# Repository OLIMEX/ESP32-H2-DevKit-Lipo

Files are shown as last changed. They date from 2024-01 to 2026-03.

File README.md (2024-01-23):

# ESP32-H2-DevKit-Lipo
Development board for ESP32-H2 SOC with BLE5 Matter, Thread, Zigbee

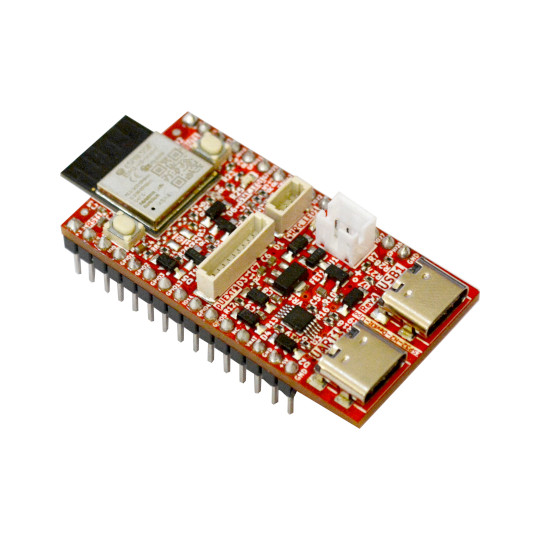
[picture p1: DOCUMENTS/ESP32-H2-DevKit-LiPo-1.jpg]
ESP32-H2-DevKit-LiPo-1


https://www.olimex.com/Products/IoT/ESP32-H2/ESP32-H2-DevKit-LiPo/open-source-hardware

Features:

* ESP32-H1-MINI-1-N4 module
* USB-C with USB to Serial converter for programming / debugging
* USB-C connected directly to ESP32-H2
* LiPo battery charger and connector
* pUEXT connector
* Qwiic/Stemma connector
* Reset button
* User button
* User LED
* all GPIOs available on two headers at 25.4 mm space
* operating temperature -40+85C
* Dimensions: 48 x 25 mm

## Licenses

* Hardware is released under CERN Open Hardware Licence Version 2 - Strongly Reciprocal, all silkscreen credits to Olimex should remain;
* Software is released under GPL3 Licensee
* Documentation is released under CC BY-SA 3.0

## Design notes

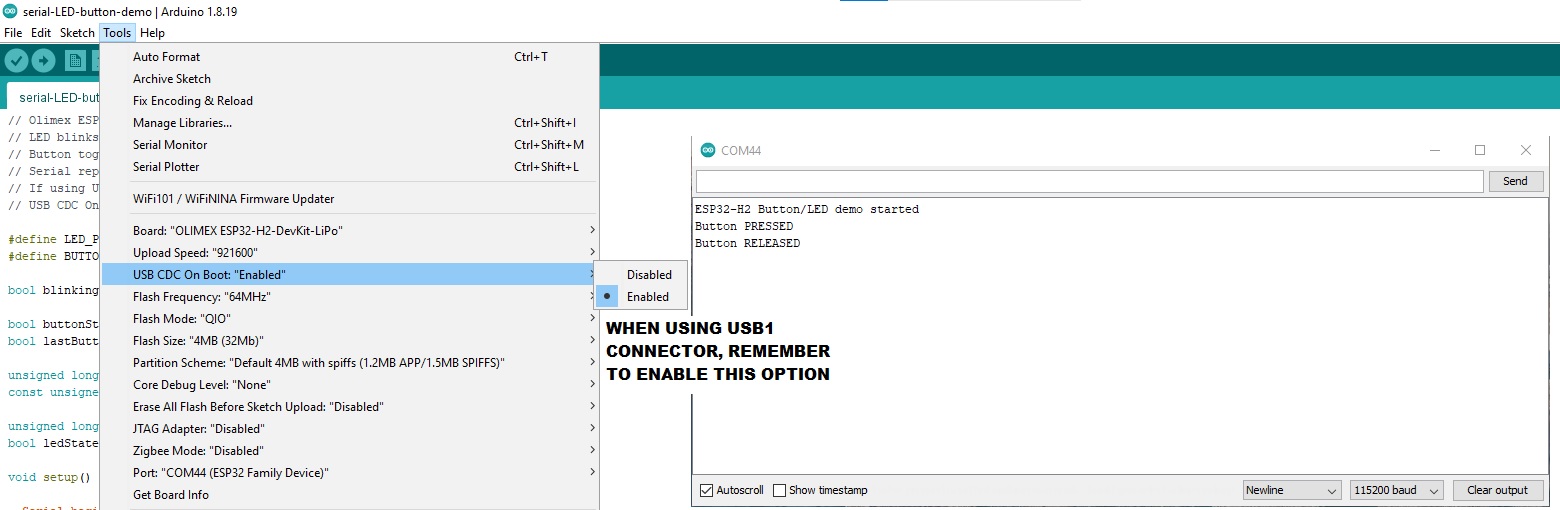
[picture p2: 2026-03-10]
SOFTWARE/ARDUINO/Serial-LED-button-demo/Settings-and-expected-outcome.jpg

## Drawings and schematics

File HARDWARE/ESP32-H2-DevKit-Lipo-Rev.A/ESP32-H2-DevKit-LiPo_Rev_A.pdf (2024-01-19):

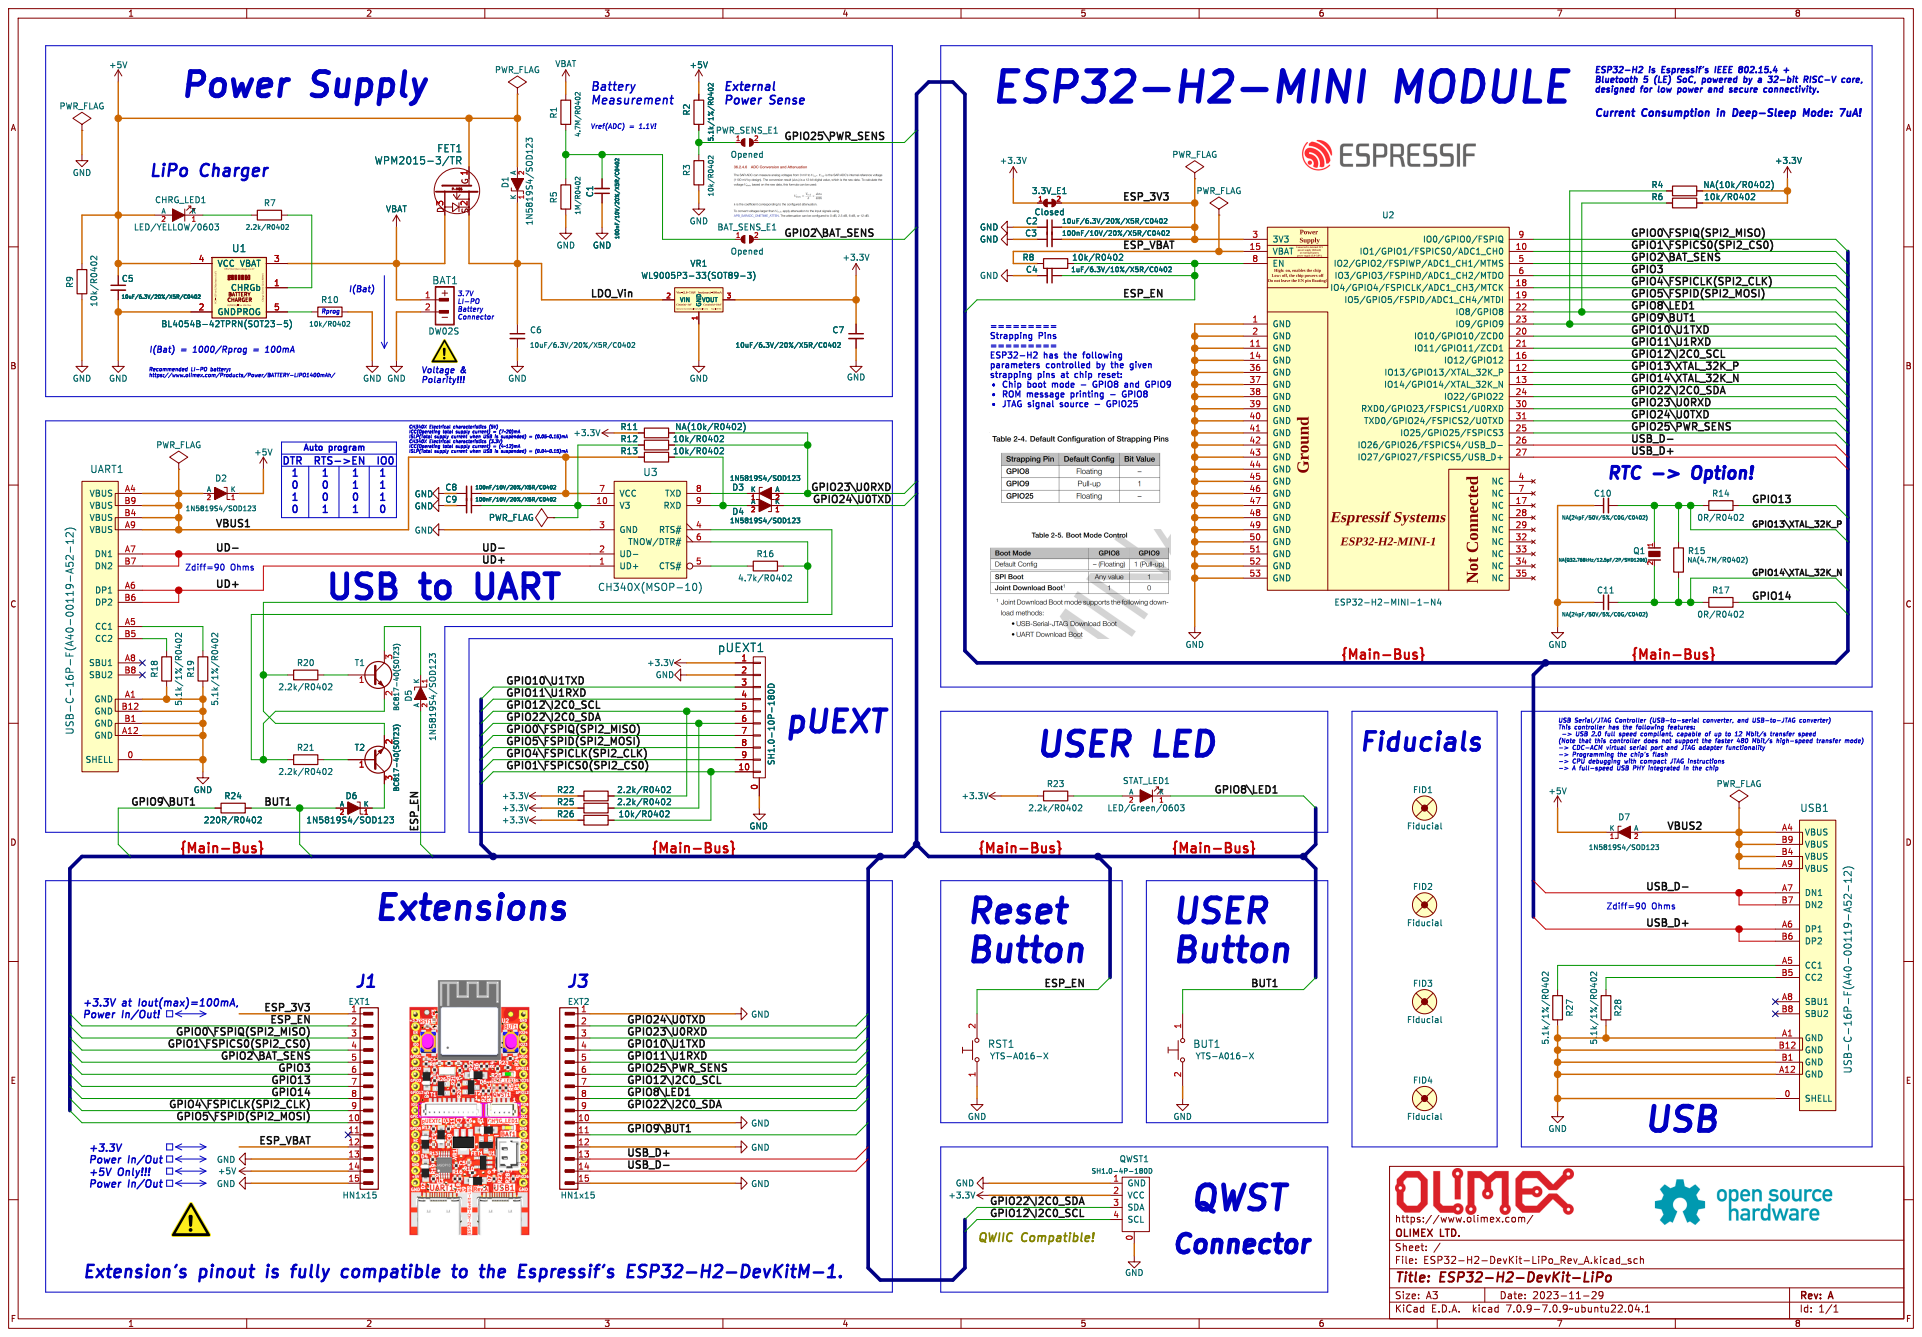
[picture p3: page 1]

Rprog 1. All SMD jumpers closed?

Connectedtointernal3V3 power supply(Default)or externalbatterypower supply(3.0~3.6V). ESP32-H2-MINI-1

QuiescentCurrent(Typ=0.3uA;Max=0.7uA) Topr=-40~85C Vin=(2.0~7.0)V GND

2 D5 1N5819S4/SOD123 C9 100nF/10V/20%/X5R/C0402 UD+ 1 V3 10 UD- 2 GND 3 RTS# 4 CTS# 5 TNOW/DTR# 6 VCC 7 TXD 8 RXD 9 U3 CH340X(MSOP-10) PWR_FLAG

Power In/Out +3.3V at Iout(max)=100mA, Power In/Out!

0 GND 1 VCC 2 SDA 3 SCL 4 QWST1

+5V Only!!! Power In/Out

Id: 1/1 Title: ESP32-H2-DevKit-LiPo

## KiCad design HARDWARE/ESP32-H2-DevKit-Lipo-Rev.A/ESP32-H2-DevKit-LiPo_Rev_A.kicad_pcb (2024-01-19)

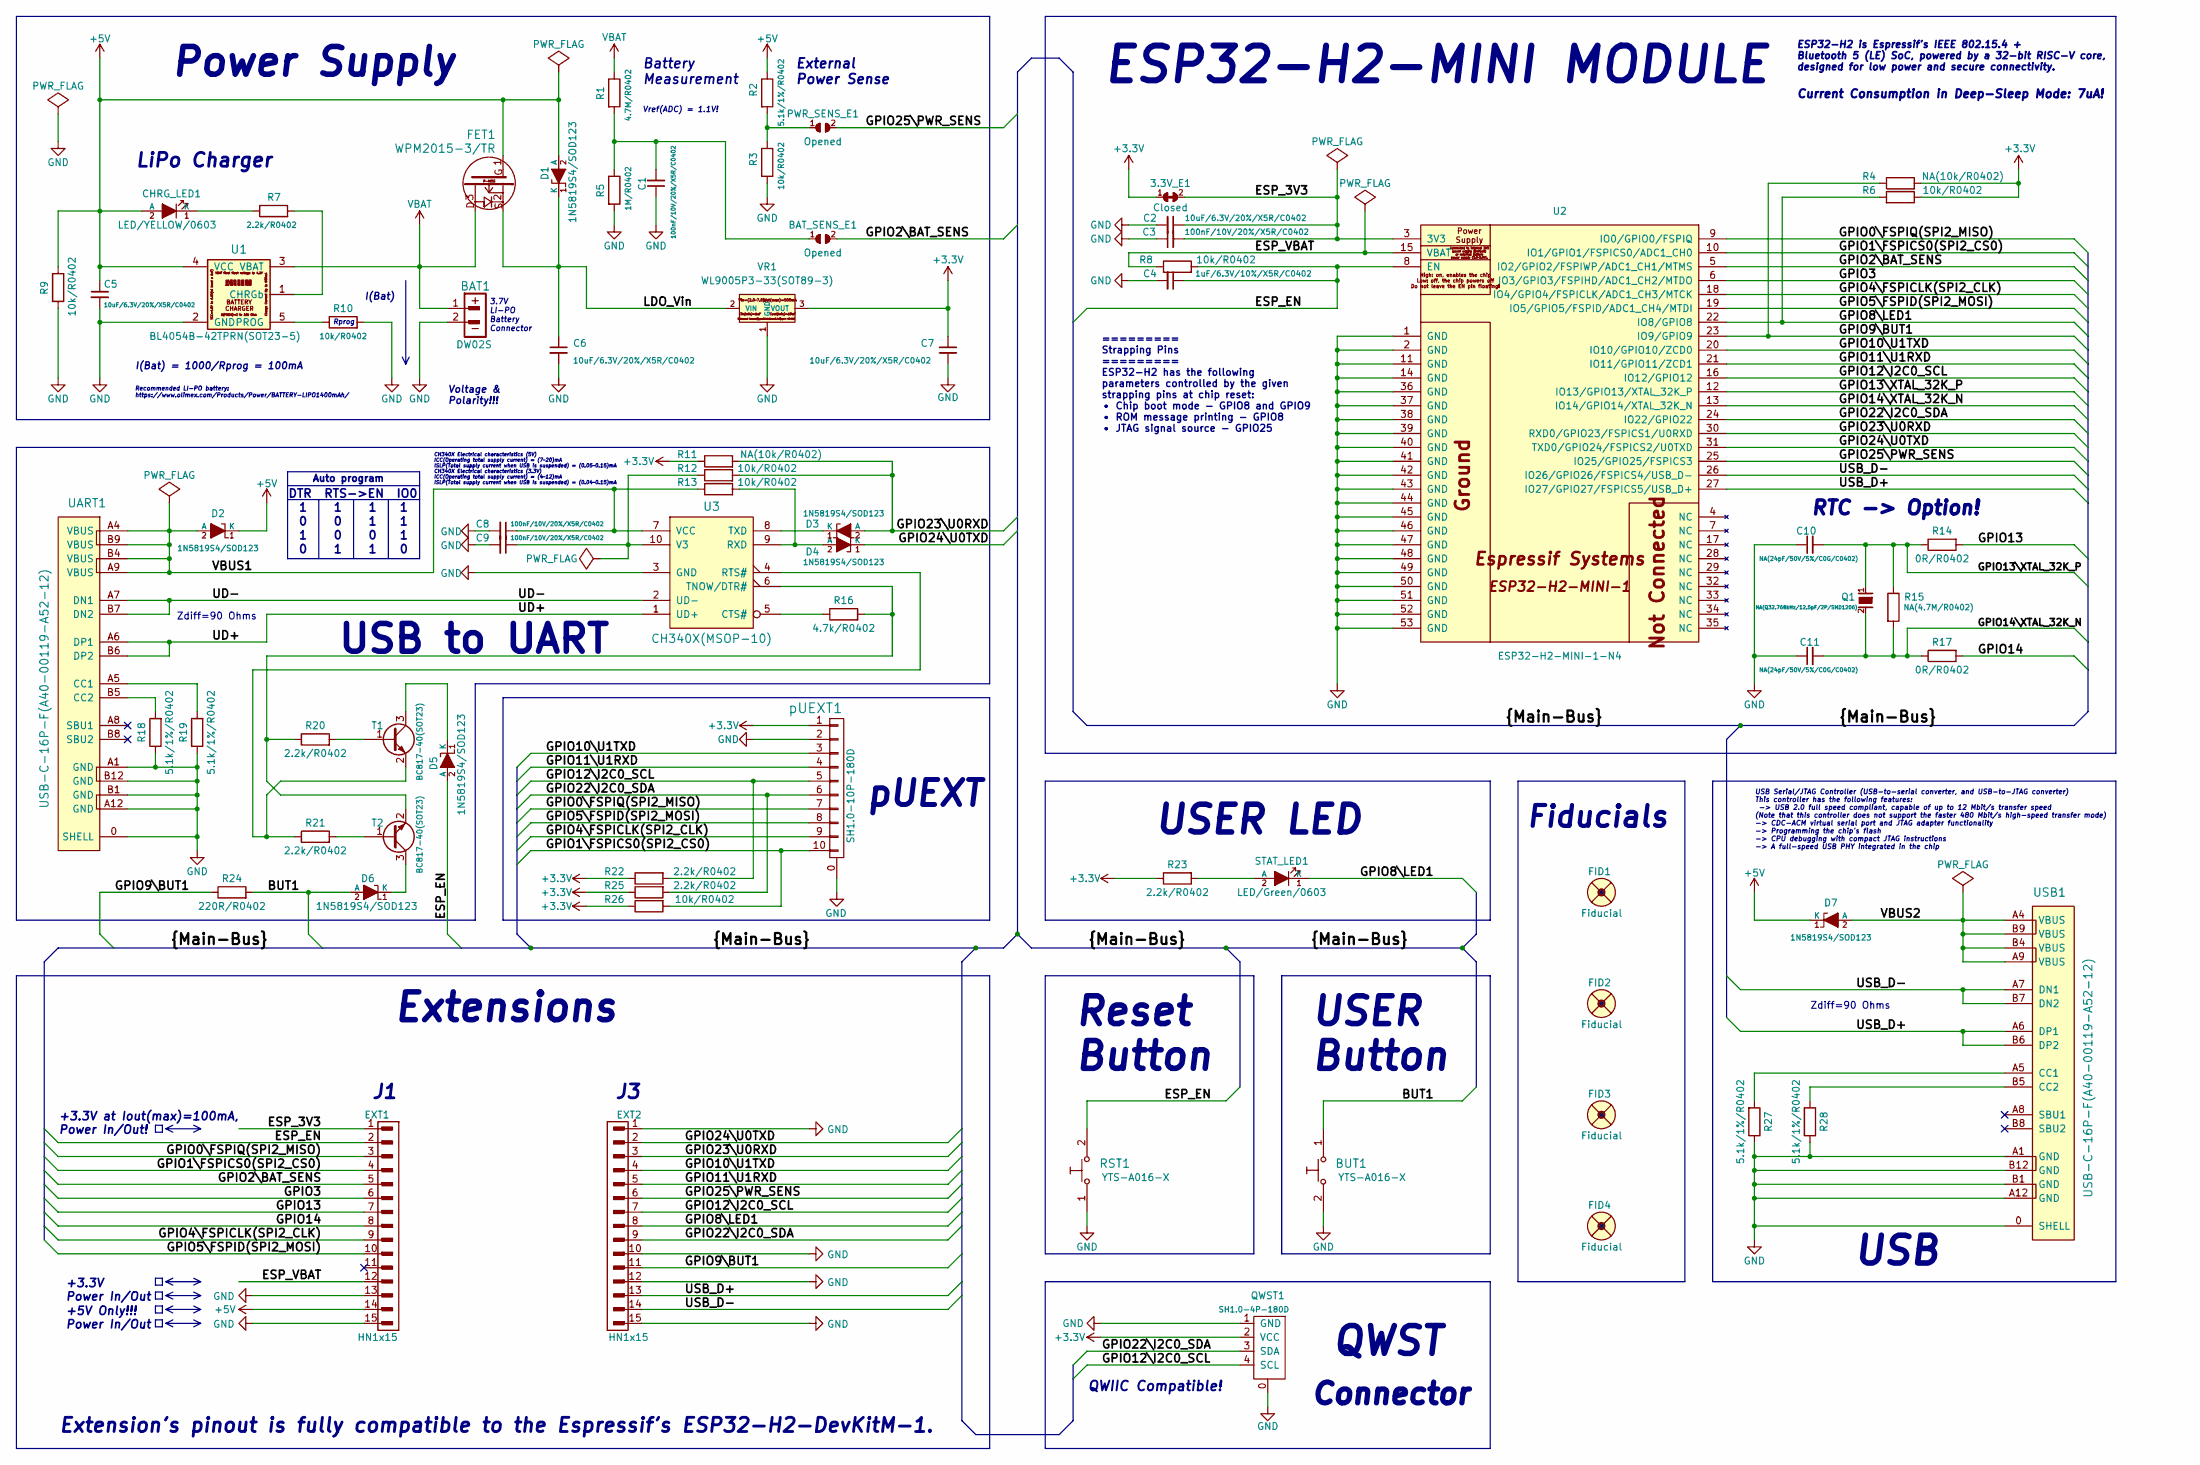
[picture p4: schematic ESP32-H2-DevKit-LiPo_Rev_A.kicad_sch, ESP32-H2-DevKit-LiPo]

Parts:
3.3V_E1: Closed; SJ_Closed
BAT1: DW02S; LIPO_BAT_VERTICAL_DW02S
BAT_SENS_E1: Opened; SJ
BUT1: YTS-A016-X
C1, C3, C8, C9: 100nF/10V/20%/X5R/C0402; C_0402_5MIL_DWS
C2, C5, C6, C7: 10uF/6.3V/20%/X5R/C0402; C_0402_5MIL_DWS
C4: 1uF/6.3V/10%/X5R/C0402; C_0402_5MIL_DWS
C10, C11: NA(24pF/50V/5%/C0G/C0402); C_0402_5MIL_DWS
CHRG_LED1: LED/YELLOW/0603; LED_0603_KA
D1, D2, D3, D4, D5, D6, D7: 1N5819S4/SOD123; SOD-123_1C-2A_KA
EXT1, EXT2: HN1x15
FET1: WPM2015-3/TR; SOT23
FID1, FID2, FID3: Fiducial; Fiducial1x3
FID4: Fiducial; Fiducial1x3_Paste
PWR_SENS_E1: Opened; SJ
Q1: NA(Q32.768kHz/12.5pF/2P/SMD1206); CM7V-T1A(Crystal_Package-1206_3.20x1.50x0.65mm)
QWST1: SH1.0-4P-180D; BM04B-SRSS-TB
R1: 4.7M/R0402; R_0402_5MIL_DWS
R2, R18, R19, R27, R28: 5.1k/1%/R0402; R_0402_5MIL_DWS
R3, R6, R8, R9, R10, R12, R13, R26: 10k/R0402; R_0402_5MIL_DWS
R4, R11: NA(10k/R0402); R_0402_5MIL_DWS
R5: 1M/R0402; R_0402_5MIL_DWS
R7, R20, R21, R22, R23, R25: 2.2k/R0402; R_0402_5MIL_DWS
R14, R17: 0R/R0402; R_0402_5MIL_DWS
R15: NA(4.7M/R0402); R_0402_5MIL_DWS
R16: 4.7k/R0402; R_0402_5MIL_DWS
R24: 220R/R0402; R_0402_5MIL_DWS
RST1: YTS-A016-X
STAT_LED1: LED/Green/0603; LED_0603_KA
T1, T2: BC817-40(SOT23); SOT23
U1: BL4054B-42TPRN(SOT23-5); SOT-23-5
U2: ESP32-H2-MINI-1-N4; ESP32-­C3-­MINI­-1
U3: CH340X(MSOP-10); MSOP-10_Pitch-0.5mm_3.00x3.00x1.00mm
UART1: USB-C-16P-F(A40-00119-A52-12); USB2.0_TYPE-C(A40-00119-A52-12)_Paste
USB1: USB-C-16P-F(A40-00119-A52-12); USB2.0_TYPE-C(A40-00119-A52-12)_Paste
VR1: WL9005P3-33(SOT89-3); SOT89-3
pUEXT1: SH1.0-10P-180D; BM10B-SRSS-TB

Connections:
+3.3V: 3.3V_E1.1, C7.1, QWST1.2 (VCC), R4.2, R6.1, R11.1, R22.1, R23.1, R25.1, R26.1, VR1.3 (VOUT), pUEXT1.1
+5V: C5.1, CHRG_LED1.2 (A), D1.2 (A), D2.1 (K), D7.1 (K), EXT1.14, FET1.1, R2.1, R9.1, U1.4 (VCC)
/BUT1: BUT1.1, D6.2 (A), R24.2
/ESP_3V3: 3.3V_E1.2, C2.1, C3.2, EXT1.1, U2.3 (3V3)
/ESP_EN: C4.1, D5.2 (A), EXT1.2, R8.2, RST1.2, U2.8 (EN)
/ESP_VBAT: EXT1.12, R8.1, U2.15 (VBAT)
/GPIO0\FSPIQ(SPI2_MISO): EXT1.3, U2.9 (IO0/GPIO0/FSPIQ), pUEXT1.7
/GPIO1\FSPICS0(SPI2_CS0): EXT1.4, R26.2, U2.10 (IO1/GPIO1/FSPICS0/ADC1_CH0), pUEXT1.10
/GPIO2\BAT_SENS: BAT_SENS_E1.2, EXT1.5, U2.5 (IO2/GPIO2/FSPIWP/ADC1_CH1/MTMS)
/GPIO3: EXT1.6, U2.6 (IO3/GPIO3/FSPIHD/ADC1_CH2/MTDO)
/GPIO4\FSPICLK(SPI2_CLK): EXT1.9, U2.18 (IO4/GPIO4/FSPICLK/ADC1_CH3/MTCK), pUEXT1.9
/GPIO5\FSPID(SPI2_MOSI): EXT1.10, U2.19 (IO5/GPIO5/FSPID/ADC1_CH4/MTDI), pUEXT1.8
/GPIO8\LED1: EXT2.8, R6.2, STAT_LED1.1 (K), U2.22 (IO8/GPIO8)
/GPIO9\BUT1: EXT2.11, R4.1, R24.1, U2.23 (IO9/GPIO9)
/GPIO10\U1TXD: EXT2.4, U2.20 (IO10/GPIO10/ZCD0), pUEXT1.3
/GPIO11\U1RXD: EXT2.5, U2.21 (IO11/GPIO11/ZCD1), pUEXT1.4
/GPIO12\I2C0_SCL: EXT2.7, QWST1.4 (SCL), R22.2, U2.16 (IO12/GPIO12), pUEXT1.5
/GPIO13: EXT1.7, R14.2
/GPIO13\XTAL_32K_P: C10.2, Q1.1, R14.1, R15.1, U2.12 (IO13/GPIO13/XTAL_32K_P)
/GPIO14: EXT1.8, R17.2
/GPIO14\XTAL_32K_N: C11.2, Q1.2, R15.2, R17.1, U2.13 (IO14/GPIO14/XTAL_32K_N)
/GPIO22\I2C0_SDA: EXT2.9, QWST1.3 (SDA), R25.2, U2.24 (IO22/GPIO22), pUEXT1.6
/GPIO23\U0RXD: D3.2 (A), EXT2.3, R11.2, R12.2, U2.30 (RXD0/GPIO23/FSPICS1/U0RXD)
/GPIO24\U0TXD: D4.1 (K), EXT2.2, U2.31 (TXD0/GPIO24/FSPICS2/U0TXD)
/GPIO25\PWR_SENS: EXT2.6, PWR_SENS_E1.2, U2.25 (IO25/GPIO25/FSPICS3)
/LDO_Vin: C6.1, D1.1 (K), FET1.2, VR1.2 (VIN)
/UD+: U3.1 (UD+), UART1.A6 (DP1), UART1.B6 (DP2)
/UD-: U3.2 (UD-), UART1.A7 (DN1), UART1.B7 (DN2)
/USB_D+: EXT2.13, U2.27 (IO27/GPIO27/FSPICS5/USB_D+), USB1.A6 (DP1), USB1.B6 (DP2)
/USB_D-: EXT2.14, U2.26 (IO26/GPIO26/FSPICS4/USB_D-), USB1.A7 (DN1), USB1.B7 (DN2)
/VBUS1: C8.1, D2.2 (A), R13.1, U3.7 (VCC), UART1.A4 (VBUS), UART1.A9 (VBUS), UART1.B4 (VBUS), UART1.B9 (VBUS)
/VBUS2: D7.2 (A), USB1.A4 (VBUS), USB1.A9 (VBUS), USB1.B4 (VBUS), USB1.B9 (VBUS)
GND: BAT1.2, BUT1.2, C1.1, C2.2, C3.1, C4.2, C5.2, C6.2, C7.2, C8.2, C9.2, C10.1, C11.1, EXT1.13, EXT1.15, EXT2.1, EXT2.10, EXT2.12, EXT2.15, QWST1.0, QWST1.1 (GND), R3.2, R5.2, R9.2, R10.2, R18.1, R19.1, R27.1, R28.1, RST1.1, U1.2 (GND), U2.1 (GND), U2.2 (GND), U2.11 (GND), U2.14 (GND), U2.36 (GND), U2.37 (GND), U2.38 (GND), U2.39 (GND), U2.40 (GND), U2.41 (GND), U2.42 (GND), U2.43 (GND), U2.44 (GND), U2.45 (GND), U2.46 (GND), U2.47 (GND), U2.48 (GND), U2.49 (GND), U2.50 (GND), U2.51 (GND), U2.52 (GND), U2.53 (GND), U3.3 (GND), UART1.0 (SHELL), UART1.A1 (GND), UART1.A12 (GND), UART1.B1 (GND), UART1.B12 (GND), USB1.0 (SHELL), USB1.A1 (GND), USB1.A12 (GND), USB1.B1 (GND), USB1.B12 (GND), VR1.1 (GND), pUEXT1.0, pUEXT1.2
unnamed: BAT_SENS_E1.1, C1.2, R1.2, R5.1
unnamed: CHRG_LED1.1 (K), R7.1
unnamed: D3.1 (K), U3.8 (TXD)
unnamed: D4.2 (A), R13.2, U3.9 (RXD)
unnamed: D5.1 (K), T1.3 (C)
unnamed: D6.1 (K), T2.3 (C)
unnamed: PWR_SENS_E1.1, R2.2, R3.1
unnamed: R23.2, STAT_LED1.2 (A)
unnamed: R20.2, T1.1 (B)
unnamed: R21.1, T1.2 (E), U3.4 (RTS#)
unnamed: R21.2, T2.1 (B)
unnamed: R16.2, R20.1, T2.2 (E), U3.6 (TNOW/DTR#)
unnamed: R7.2, U1.1 (CHRGb)
unnamed: R10.1, U1.5 (PROG)
unnamed: R16.1, U3.5 (CTS#)
unnamed: C9.1, R12.1, U3.10 (V3)
unnamed: R19.2, UART1.A5 (CC1)
unnamed: R18.2, UART1.B5 (CC2)
unnamed: R27.2, USB1.A5 (CC1)
unnamed: R28.2, USB1.B5 (CC2)
VBAT: BAT1.1, FET1.3, R1.1, U1.3 (VBAT)

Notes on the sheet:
pUEXT
I(Bat) = 1000/Rprog = 100mA
DTR RTS->EN IO0
I(Bat)
========= Strapping Pins ========= ESP32-H2 has the following parameters controlled by the given strapping pins at chip reset: • Chip boot mode - GPIO8 and GPIO9 • ROM message printing - GPIO8 • JTAG signal source - GPIO25
LiPo Charger
External Power Sense
USB
USB to UART
Vref(ADC) = 1.1V!
RTC -> Option!
Reset Button
Extensions
USER LED
Zdiff=90 Ohms
Fiducials
Extension's pinout is fully compatible to the Espressif's ESP32-H2-DevKitM-1.
Auto program
CH340X Electrical characteristics (5V) ICC(Operating total supply current) = (7~20)mA ISLP(Total supply current when USB is suspended) = (0.05~0.15)mA CH340X Electrical characteristics (3.3V) ICC(Operating total supply current) = (4~12)mA ISLP(Total supply current when USB is suspended) = (0.04~0.1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
+5V Only!!! Power In/Out
Rprog
Battery Measurement
QWST
ESP32-H2-MINI MODULE
USB Serial/JTAG Controller (USB-to-serial converter, and USB-to-JTAG converter) This controller has the following features: -> USB 2.0 full speed compliant, capable of up to 12 Mbit/s transfer speed (Note that this controller does not support the faster 480 Mbit/s high-speed transfer mode) -> CDC-A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
QWIIC Compatible!
3.7V LI-PO Battery Connector
Connector
ESP32-H2 is Espressif's IEEE 802.15.4 + Bluetooth 5 (LE) SoC, powered by a 32-bit RISC-V core, designed for low power and secure connectivity.
Power Supply
Voltage & Polarity!!!
+3.3V Power In/Out
Current Consumption in Deep-Sleep Mode: 7uA!
USER Button
+3.3V at Iout(max)=100mA, Power In/Out!
Recommended LI-PO battery: https://www.olimex.com/Products/Power/BATTERY-LIPO1400mAh/

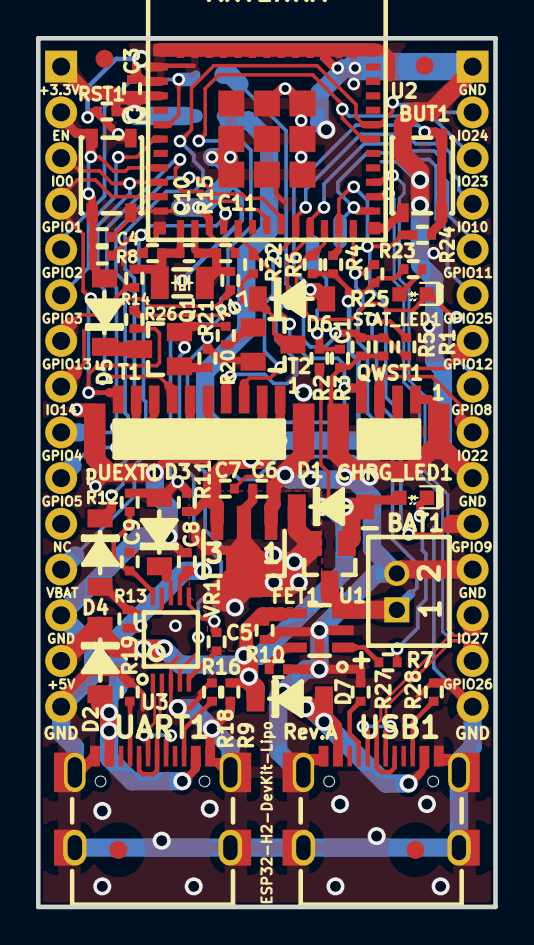
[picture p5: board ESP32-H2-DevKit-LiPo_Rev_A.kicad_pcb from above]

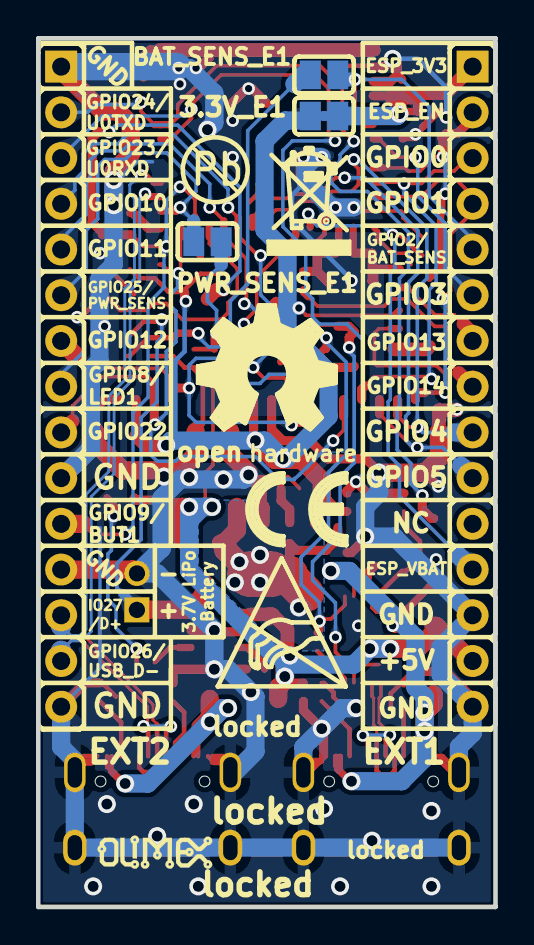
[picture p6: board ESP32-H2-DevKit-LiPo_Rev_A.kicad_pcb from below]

Board: 2 copper layers, 25.4 x 48.3 mm, 78 parts (11 on the bottom side), 54 nets.

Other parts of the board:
Logo_OLIMEX_80: Logo_OLIMEX_80
Sign_Antistatic: Sign_Antistatic
Sign_CE: CE_Sign
Sign_OSHW_8x8: Sign_OSHW_8x8
Sign_PB-Free: Sign_PB-Free
Sign_RecycleBin_1: Sign_RecycleBin_1

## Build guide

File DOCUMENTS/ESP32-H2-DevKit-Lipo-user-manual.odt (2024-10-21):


ESP32-H2-DevKit-Lipo

User Manual

Document revision 2.1, October 2024 | www.olimex.com

# What is ESP32-H2-DevKit-Lipo

ESP32-H2 combines IEEE 802.15.4 connectivity with Bluetooth 5 (LE).

The SoC is powered by a single-core, 32-bit RISC-V microcontroller that can be clocked up to 96 MHz.

The ESP32-H2 has been designed to ensure low power consumption and security for connected devices.

ESP32-H2 has 320 KB of SRAM with 16 KB of Cache, 128 KB of ROM, 4 KB LP of memory, and a built-in 2 MB or 4 MB SiP flash.

It has 19 programmable GPIOs with support for ADC, SPI, UART, I2C, I2S, RMT, GDMA and LED PWM.

Bluetooth supports: Bluetooth Low Energy (Bluetooth 5.3 certified), Bluetooth mesh, Bluetooth Low Energy long range (Coded PHY, 125 Kbps and 500 Kbps), Bluetooth Low Energy high speed (2 Mbps)

IEEE Standard 802.15.4-2015 compliant

Supports Thread 1.3

Supports Zigbee 3.0

Supports Matter

Supports HomeKit, MQTT

## ESP32-H2-DevKit-Lipo features

- ESP32-H2 embedded, RISC-V single-core 32-bit LX7 microprocessor, up to 96 MHz, 128 KB ROM, 320 KB SRAM, 4 KB LP Memory, 4 MB flash
- USB-C with USB to Serial converter for programming / debugging
- USB-C connected directly to ESP32-H2
- LiPo battery charger and connector
- pUEXT UEXT connector (https://www.olimex.com/Products/Modules/UEXT/)
- Qwiic/Stemma connector
- Reset button
- User button
- User LED
- All GPIOs available on two headers at 25.4 mm space
- Dimensions: 48 x 25 mm
- Operating temperature: -40+85C

## Order codes for ESP32-H2-DevKit-Lipo and accessories:

ESP32-H2-DevKit-Lipo (https://www.olimex.com/Products/IoT/ESP32-H2/ESP32-H2-DevKit-LiPo/open-source-hardware) commercial grade -40+85C board with internal antenna

USB-CABLE-A-TO-C-1M (https://www.olimex.com/Products/Components/Cables/USB-CABLE-A-TO-C-1M/) USB-C cable

BATTERY-LIPO1400mAh (https://www.olimex.com/Products/Power/Lipo-battery/BATTERY-LIPO1400mAh/) - Lipo battery 3.7V 1400mAh – note these batteries can be shipped only by ground so we can deliver only to EU destinations.

UEXT modules (https://www.olimex.com/Products/Modules/) - different sensors, relays, LCDs, RTC, GSM, GPS etc accessories which can be connected to UEXT connector

# HARDWARE

## ESP32-H2-DevKit-Lipo layout:

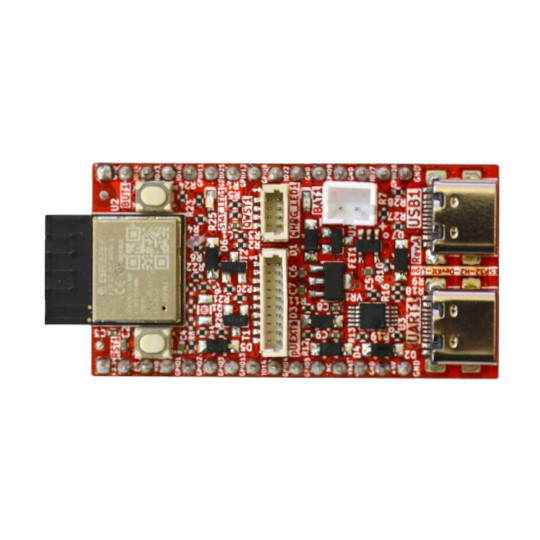
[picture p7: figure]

ESP32-H2-MINI-1-N4

RESET button

pUEXT connector

USB-C with USB-to-Serial converter for debug and programming

User Button

User LED

QWIIC-STEMMA

Battery Charge LED

LiPo battery

connector

USB-C serial/JTAG

## ESP32-H2-DevKit-Lipo GPIOs:

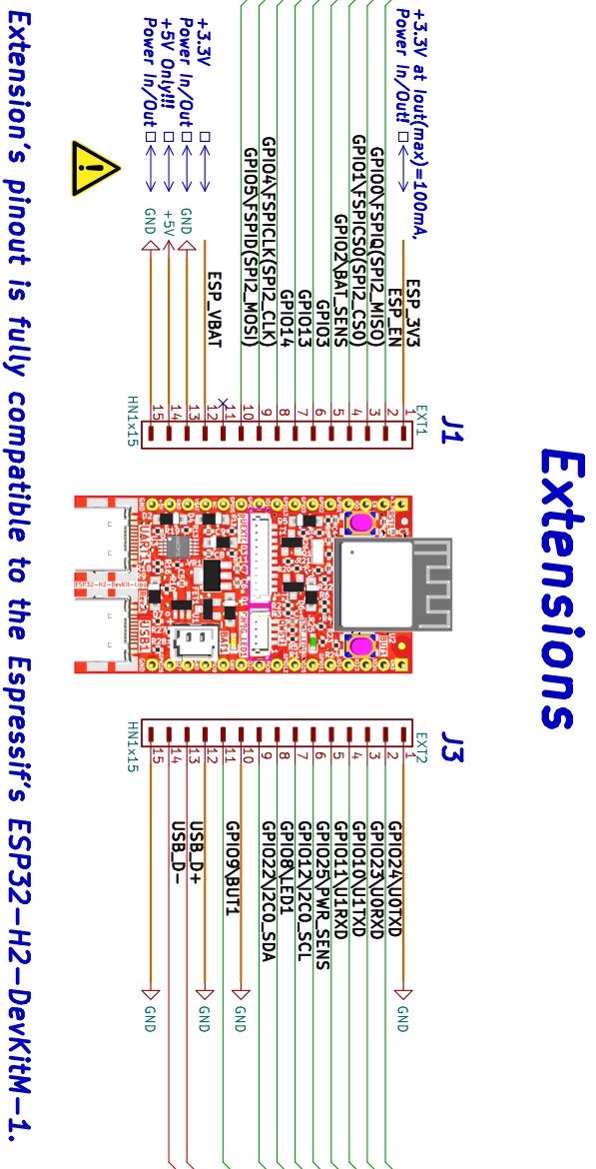
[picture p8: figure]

## ESP32-H2-DevKit-Lipo schematics:

ESP32-H2-DevKit-Lipo (https://www.olimex.com/Products/IoT/ESP32-H2/ESP32-H2-DevKit-LiPo/open-source-hardware) latest schematic is on GitHub (https://github.com/OLIMEX/ESP32-H2-DevKit-Lipo)

## ESP32-H2-DevKit-Lipo power supply:

ESP32-H2-DevKit-Lipo (https://www.olimex.com/Products/IoT/ESP32-H2/ESP32-H2-DevKit-LiPo/open-source-hardware) can be powered by either:

- USB-C connectors USB1 or UART1
- EXT1 pin 14 (+5V)
- LiPo battery

The switch between these is automatically without voltage drop.

Power consumption of ESP32-H2-DevKit-Lipo is less 10uA in deep sleep mode.

## UEXT connector:

UEXT connector stands for Universal EXTension connector and contains +3.3V, GND, I2C, SPI, UART signals.

pUEXT is 1mm step boxed plastic connector. All signals are with 3.3V levels.

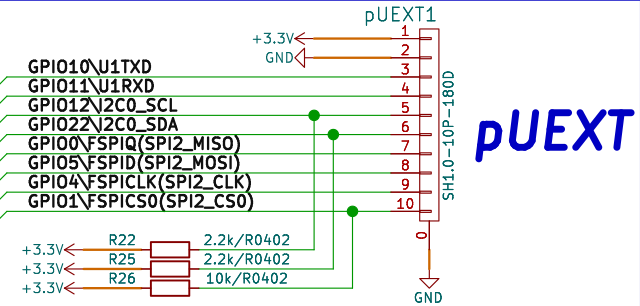
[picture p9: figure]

Olimex has developed number of MODULES (https://www.olimex.com/Products/Modules/) with this connector. There are temperature, humidity, pressure, magnetic field, light sensors. Modules with LCDs, LED matrix, Relays, Bluetooth, Zigbee, WiFi, GSM, GPS, RFID, RTC, EKG, sensors and etc.

## External power sense and battery measurement:

Battery measurements are disabled by default to provide more free GPIOs but they can be enabled by closing a couple of jumpers. In order to measure the battery you first need to close SMT jumper BAT_SENS_E (solder its pads together). This will allow you to measure the battery voltage via ESP32-H2 pin GPIO2. Notice that the board has voltage divider formed by R1 and R5(1M and 4.7M).

The board also has external power sense – aka whether you have external power or board is powered via battery (it is good idea to know if you have external power so you can put the board in some power saving mode or perform some saves). This can be enabled if you close jumper PWR_SENSE_E1 (again solder its pads together). This will allow you to determine if external power is present via pin GPIO25.

After the jumper or jumpers are closed you need some simple code to read voltage and detect external power presence. Code in Arduino (with Espressif ESP32 package installed) should be similar to this:

#define POWER_SENSE 25
#define BATTERY 2

void setup()
{
Serial.begin (115200);
pinMode (POWER_SENSE, INPUT);
pinMode (BATTERY, INPUT);
}

void loop()
{
Serial.print ("External power sense: ");
Serial.println (digitalRead (POWER_SENSE));

Serial.print ("Battery measurement: ");
Serial.print (analogReadMilliVolts (BATTERY)*5.7);
Serial.println (" mV");
Serial.println ();
delay (1000);
}
This would give good enough reading, but value will fluctuate a bit (this is normal for this ADC). If the fluctuations bother you try filling an array and giving average.
I also recommend you reading this bit about Arduino ADC libraries for ESP32 (it also mentions S2 specifics), it explains the functions, the options, and gives some more complex examples at the end:

https://espressif-docs.readthedocs-hosted.com/projects/arduino-esp32/en/latest/api/adc.html

# SOFTWARE

For regular programming via USB type C cable, use USB connector named “UART1”.

ESP32-H2-DevKit-Lipo is supported by

- Espressif ESP-IDF (https://docs.espressif.com/projects/esp-idf/en/latest/esp32/get-started/)
- Arduino IDE (https://github.com/OLIMEX/ESP32-POE/tree/master/SOFTWARE/ARDUINO)

The board has own config in the ESP32 package for Arduino IDE:

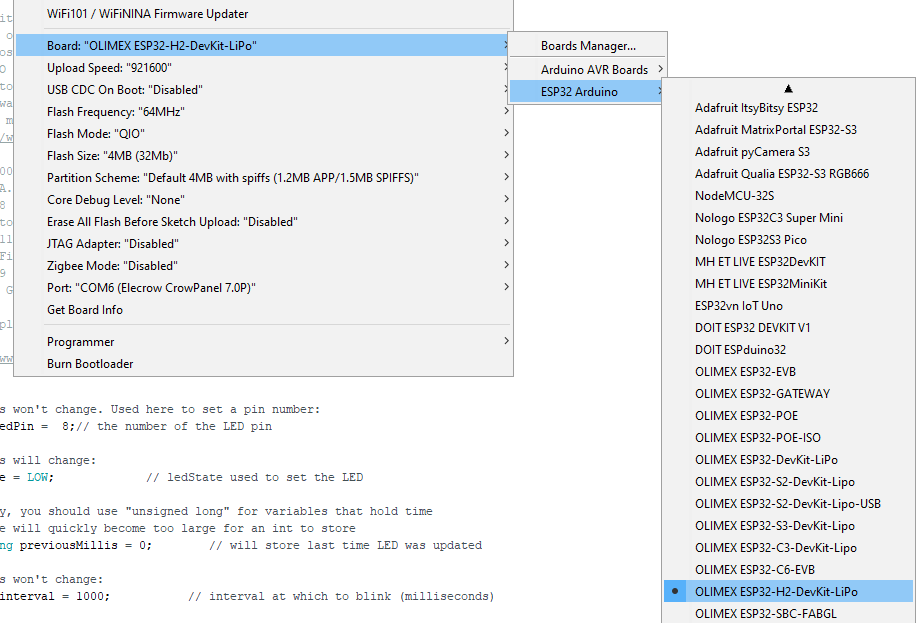
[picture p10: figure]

# Document Revision History

Revision 2.1 October 2024

- Fixed wrong voltage divider multiplier

- Improved information about ADC and battery measurements

Revision 2.0 August 2024

- added info about the battery measurement

Revision 1.0 January 2024

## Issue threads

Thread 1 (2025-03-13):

Enable charging circuit

aaronkbutler, 2025-03-13:
How can I enable the charging circuit? The battery seems to provide power just fine, but plugging in USB while the battery is also plugged in doesn’t seem to charge the LiPO battery.

Closed 2025-03-18.

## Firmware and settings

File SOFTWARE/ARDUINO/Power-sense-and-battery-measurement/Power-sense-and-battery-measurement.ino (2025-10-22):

// ==========================================================
// ESP32-H2-DevKit-LiPo Battery and Power Sense Demo
// ----------------------------------------------------------
// First make sure jumpers BAT_SENS_E1 and 
// PWR_SENS_E1 are closed (pads soldered together)!
//
// In Tools -> Board select ESP32H2 Dev Module and Enable CDC on boot!
//
// External Power Sense: GPIO25
// Battery Measurement:  GPIO2
// User Button (BUT1):   GPIO9
// LED:                  GPIO8
//
// Resistor divider coefficient = (R5 + R1) / R5 = 5.7
// Maximum battery voltage = 4.2V
//
// ➤ Press BUT1 for 2–6 seconds → enter ADC calibration mode
// ➤ Press BUT1 for >6 seconds → reset stored calibration factor
// ➤ Measure the battery with a multimeter *while still connected*
//    (at battery contacts on the bottom of the board)
// ➤ LED blinks fast in calibration mode and flashes 3× on success
// ➤ LED flashes 5× quickly on calibration reset
// ==========================================================

#include <Preferences.h>

#define POWER_SENSE_PIN   25
#define BATTERY_PIN       2
#define BUTTON_PIN        9
#define LED_PIN           8

// Divider ratio (R5+R1)/R5 = 5.7
float resistorCoeff = 5.7;

// ADC calibration coefficient (stored in flash)
Preferences prefs;
float calibrationFactor = 1.0;

// LED control
unsigned long lastBlink = 0;
bool ledState = false;

// Calibration mode flag
bool calibrating = false;

// Button press tracking
unsigned long buttonPressStart = 0;
bool buttonPressed = false;

// ----------------------------------------------------------
// Setup
// ----------------------------------------------------------
void setup() {
  Serial.begin(115200);
  pinMode(POWER_SENSE_PIN, INPUT);
  pinMode(BATTERY_PIN, INPUT);
  pinMode(BUTTON_PIN, INPUT_PULLUP);
  pinMode(LED_PIN, OUTPUT);

  prefs.begin("adc-calib", false);
  calibrationFactor = prefs.getFloat("factor", 1.0);

  Serial.println("\nESP32-H2-DevKit-LiPo Power & Battery Sense");
  Serial.println("------------------------------------------------");
  Serial.print("Resistor divider coefficient: ");
  Serial.println(resistorCoeff);
  Serial.print("Calibration factor: ");
  Serial.print(calibrationFactor);
  if (prefs.isKey("factor"))
    Serial.println("  (loaded from flash)");
  else
    Serial.println("  (using default)");
  Serial.println("------------------------------------------------\n");
}

// ----------------------------------------------------------
// Main loop
// ----------------------------------------------------------
void loop() {
  unsigned long now = millis();

  // LED blinking pattern
  unsigned long interval = calibrating ? 150 : 800;
  if (now - lastBlink > interval) {
    ledState = !ledState;
    digitalWrite(LED_PIN, ledState);
    lastBlink = now;
  }

  // Button press detection
  if (digitalRead(BUTTON_PIN) == LOW) {
    if (!buttonPressed) {
      buttonPressStart = now;
      buttonPressed = true;
    }
  } else {
    if (buttonPressed) {
      unsigned long pressDuration = now - buttonPressStart;

      if (pressDuration >= 2000 && pressDuration < 6000) {
        // Enter calibration mode
        startCalibration();
      } else if (pressDuration >= 6000) {
        // Reset calibration
        calibrationFactor = 1.0;
        prefs.clear();
        Serial.println("\n*** Calibration data reset! Using default = 1.0 ***");

        // Flash LED 5× to confirm reset
        for (int i = 0; i < 5; i++) {
          digitalWrite(LED_PIN, HIGH);
          delay(150);
          digitalWrite(LED_PIN, LOW);
          delay(150);
        }
      }

      buttonPressed = false;
    }
  }

  // Regular measurement mode
  if (!calibrating) {
    Serial.print("External Power Sense: ");
    Serial.println(digitalRead(POWER_SENSE_PIN));

    int mv = analogReadMilliVolts(BATTERY_PIN);
    float actualMv = mv * resistorCoeff * calibrationFactor;

    Serial.print("Battery Voltage: ");
    Serial.print(actualMv);
    Serial.println(" mV\n");
    delay(500);
  }
}

// ----------------------------------------------------------
// Calibration mode
// ----------------------------------------------------------
void startCalibration() {
  calibrating = true;
  Serial.println("\n=== ADC Calibration Mode ===");
  Serial.println("Measure the battery with a multimeter (while connected).");
  Serial.println("Enter the measured voltage in millivolts (e.g., 4120):");

  while (true) {
    if (Serial.available()) {
      String input = Serial.readStringUntil('\n');
      input.trim();
      float measuredMv = input.toFloat();

      if (measuredMv > 0) {
        int rawMv = analogReadMilliVolts(BATTERY_PIN) * resistorCoeff;
        calibrationFactor = measuredMv / rawMv;

        prefs.putFloat("factor", calibrationFactor);
        Serial.print("Calibration complete! Factor saved: ");
        Serial.println(calibrationFactor);

        // Flash LED 3× to confirm success
        for (int i = 0; i < 3; i++) {
          digitalWrite(LED_PIN, HIGH);
          delay(150);
          digitalWrite(LED_PIN, LOW);
          delay(150);
        }

        calibrating = false;
        Serial.println("Exiting calibration mode.\n");
        break;
      } else {
        Serial.println("Invalid input. Please enter numeric millivolts (e.g., 4120):");
      }
    }
  }
}

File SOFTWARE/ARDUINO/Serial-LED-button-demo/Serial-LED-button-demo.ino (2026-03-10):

// Olimex ESP32-H2-DevKit-LiPo demo
// LED blinks
// Button toggles LED blinking ON/OFF
// Serial reports button status
// If using USB1 remember to have
// USB CDC On Boot: "Enabled"

#define LED_PIN     8
#define BUTTON_PIN  9

bool blinkingEnabled = true;

bool buttonState;
bool lastButtonReading;

unsigned long lastDebounceTime = 0;
const unsigned long debounceDelay = 25;

unsigned long lastBlink = 0;
bool ledState = false;

void setup() {

  Serial.begin(115200);

  pinMode(LED_PIN, OUTPUT);
  pinMode(BUTTON_PIN, INPUT_PULLUP);

  digitalWrite(LED_PIN, HIGH); // LED OFF (active LOW)

  buttonState = digitalRead(BUTTON_PIN);
  lastButtonReading = buttonState;

  Serial.println("ESP32-H2 Button/LED demo started");
}

void loop() {

  // -------- BUTTON READ --------
  bool reading = digitalRead(BUTTON_PIN);

  if (reading != lastButtonReading) {
    lastDebounceTime = millis();
  }

  if ((millis() - lastDebounceTime) > debounceDelay) {

    if (reading != buttonState) {

      buttonState = reading;

      if (buttonState == LOW) {
        Serial.println("Button PRESSED");
        blinkingEnabled = !blinkingEnabled;   // toggle LED blinking
      } else {
        Serial.println("Button RELEASED");
      }

    }
  }

  lastButtonReading = reading;


  // -------- LED BLINK --------
  if (blinkingEnabled) {

    if (millis() - lastBlink > 500) {

      lastBlink = millis();
      ledState = !ledState;

      digitalWrite(LED_PIN, ledState ? LOW : HIGH); // active LOW LED
    }

  } else {

    digitalWrite(LED_PIN, HIGH); // LED OFF
  }

}

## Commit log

2024-01-19 initial upload
    [ESP32-H2-DevKit-LiPo_Rev_A-B_Cu.gbr, ESP32-H2-DevKit-LiPo_Rev_A-B_Mask.gbr, ESP32-H2-DevKit-LiPo_Rev_A-B_Paste.gbr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]
2025-10-22 New demo
    Power sense and battery measurement advanced demo
2026-03-09 Create LED-button-demo.ino
    Simple LED and button demo

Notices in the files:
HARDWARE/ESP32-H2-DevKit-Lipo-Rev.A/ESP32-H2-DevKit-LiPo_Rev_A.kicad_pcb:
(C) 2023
